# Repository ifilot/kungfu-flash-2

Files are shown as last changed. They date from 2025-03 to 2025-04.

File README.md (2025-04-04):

# Kung Fu Flash 2 - Adapted version

Cartridge for the Commodore 64 that packs a punch.

> [!IMPORTANT]  
> This repository is a fork of [Kung Fu Flash 2](https://github.com/KimJorgensen/KungFuFlash2).
> A number of changes have been made to the original design, mainly focusing
> on using so-called "BASIC" parts to reduce upon the cost of using the JLCPCB
> assembly service.
>
> In the folder [hardware/production](hardware/production) one can find the
> BOM and CPL files for using the JLCPCB assembly service.
>
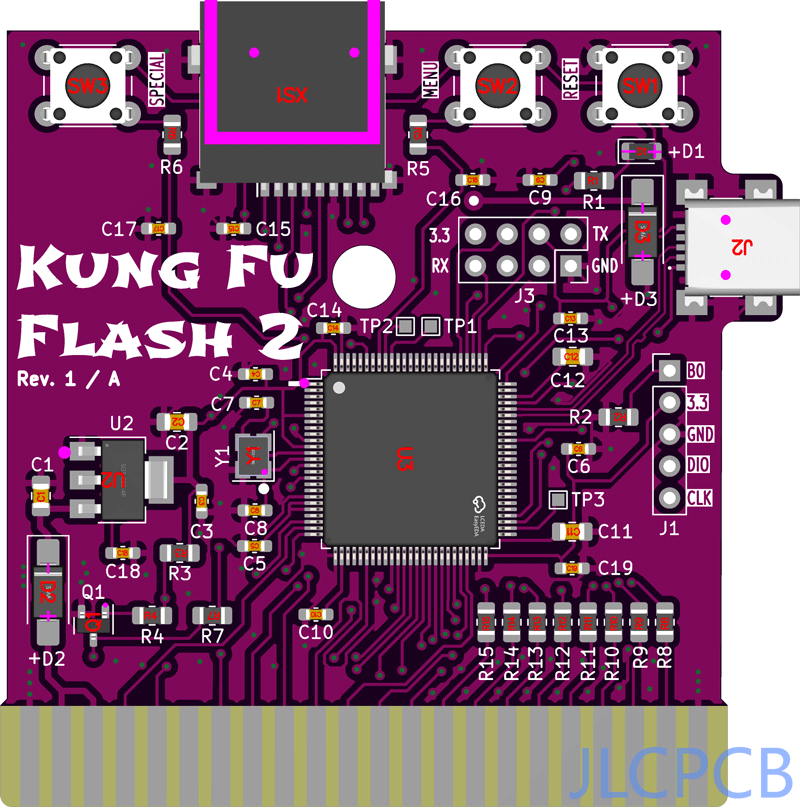
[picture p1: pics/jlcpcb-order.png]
jlcpcb order image
> 

**The text below has been copied verbatim from the original repository**

Kung Fu Flash 2 is the big brother of [Kung Fu Flash](https://github.com/KimJorgensen/KungFuFlash). It has a faster microcontroller with more memory and I/O pins, allowing for additional functionality.

**Currently, this project is considered experimental** and provides the same features as Kung Fu Flash, with these notable exceptions:

* CRT files are loaded into RAM, not flash, making large CRT files startup faster. However, changes to EasyFlash cartridges are lost if power is turned off, unless saved via the menu first
* The cartridge detects if the C64/C128 is reset. This allows the use of an additional reset button on the C64 or the built-in reset button on the C128
* REU emulation has been added

Kung Fu Flash 2 Launcher

Kung Fu Flash 2 can emulate different cartridge types, load PRG files and use D64 disk images.
Just place your desired CRT, PRG or D64 files on a FAT formatted microSD card and use the built-in launcher to execute them.

## Hardware

There are three buttons on the cartridge; a reset button, a menu button for starting the launcher, and a special button that is used by the freezer cartridges.

Cartridge Case

The form factor is similar to Kung Fu Flash and it should be possible to use the same cartridge cases.
It could be the Stumpy Cartridge Case from TFW8b or the 3D printed cartridge case designed by bigby, [see here](https://www.thingiverse.com/thing:4153414).

Kung Fu Flash 2 PCB

The gerber files and BOM can be found [here](https://github.com/KimJorgensen/KungFuFlash2/releases/tag/v2.00).

## Supported Cartridges

The following cartridge types are currently supported:

* Generic cartridge (8k, 16k, Ultimax)
* Action Replay v4.x/v5/v6
* KCS Power Cartridge
* Final Cartridge III(+)
* Simons' BASIC
* Fun Play, Power Play
* Super Games
* Ocean type 1
* Epyx Fastload
* C64 Game System, System 3
* WarpSpeed
* Dinamic
* Zaxxon, Super Zaxxon
* Magic Desk, Domark, HES Australia
* Super Snapshot v5
* Comal-80
* Ross
* EasyFlash
* Prophet64
* Freeze Frame
* Freeze Machine
* MACH 5
* Pagefox
* RGCD, Hucky
* Drean
* C128 Generic cartridge (external function ROM)
* WarpSpeed 128

## Supported File Types

The following file types are currently supported:

* Cartridge (CRT)
* C64/C128 generic cartridge (ROM, BIN)
* Disk image (D64, D71, D81)
* Tape image (T64)
* Program (PRG, P00)
* Firmware update (UPD)
* Text document (TXT, NFO, 1ST)

## REU Emulation

Kung Fu Flash 2 can emulate a 1 Mb REU (RAM Expansion Unit) simultaneously with disk drive emulation.
The REU is enabled in the settings menu (F5) and active when:

* A program is executed using the default option (RETURN)
* A disk image or directory is mounted using "Mount" in the file options menu (SHIFT+RETURN)
* BASIC is started via F6 (C128) or F7 (C64) in the launcher

The REU will not be active when emulating cartridges (CRT files)

## USB Port

The USB port allows programs or disk images to be transferred from/to a PC using the EasyFlash 3 USB protocol.
The USB port is active when:

* The Kung Fu Flash 2 launcher is running
* A program is started using "Load" in the file options menu (SHIFT+RETURN)
* BASIC is started via F7 in the launcher **and** REU emulation is disabled in the settings menu (F5)

Kung Fu Flash 2 shows up as a standard serial port when connected to a PC not requiring any custom drivers to be installed.
This means, however, that the EasyFlash 3 program on the PC side must be modified to support Kung Fu Flash.

The repository of the original Kung Fu Flash contains a modified version of [EasyFlash 3 USB Utilities](https://github.com/KimJorgensen/KungFuFlash/tree/master/3rd_party/ef3utils)
and [EasyFlash 3 BBS](https://github.com/KimJorgensen/KungFuFlash/tree/master/3rd_party/ef3bbs) which will also work with the Kung Fu Flash 2.

## Firmware Update

Just place the KungFuFlash_v2.xx.upd file on the SD card and select the file in the launcher to initiate the firmware update.
The newest firmware can be found [here](https://github.com/KimJorgensen/KungFuFlash2/releases/).

For initial firmware installation, [see here](firmware/README.md).

## Limitations

Kung Fu Flash 2 is a so called Software Defined Cartridge where a fast microcontroller emulates cartridge hardware in software.
This makes it extremely flexible, allowing different cartridge types to be supported at a relative low cost.

However, it can be challenging to get the C64 bus timing correct in software and in some places the timing is very close to the limit.
Even though Kung Fu Flash 2 has been tested on different models of the Commodore 64, there is a chance that it doesn't work correctly on your specific model, or requires [phi2 offset adjustment](firmware/README.md#diagnostic).
Use it at your own risk!

Kung Fu Flash 2 will work with the PAL and NTSC version of the Commodore 64 or Commodore 128.

Disk drive emulation is using kernal vectors and will not work with fast loaders or software that uses direct hardware access which a lot of games does.
Currently REL files are not supported and only a subset of the Commodore DOS commands are supported.

## Thanks

Kung Fu Flash 2 was based on or uses other open source projects:

* [Kung Fu Flash](https://github.com/KimJorgensen/KungFuFlash)
* [EasyFlash 3](https://bitbucket.org/skoe/easyflash) by Thomas Giesel
* [Draco Browser](https://csdb.dk/release/?id=89910) by Sascha Bader
* [fatfs-stm32](https://github.com/colosimo/fatfs-stm32) by Aurelio Colosimo
* [FatFs](http://elm-chan.org/fsw/ff/00index_e.html) by ChaN
* [libusb_stm32](https://github.com/dmitrystu/libusb_stm32) by Dmitry Filimonchuk
* [OpenC64Cart](https://github.com/SukkoPera/OpenC64Cart) by Giorgioggì
* [Disk2easyflash](https://csdb.dk/release/?id=150323) by ALeX Kazik

and a few others. Please check the individual files for their license.

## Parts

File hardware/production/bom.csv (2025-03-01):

Designator | Footprint | Quantity | Value | LCSC Part #
C1, C2 | 0805 | 2 | 10uF | C15850
C10, C13, C14, C15, C16, C17, C18, C19, C3, C4, C5, C6, C9 | 0603 | 13 | 100nF | C14663
C11, C12 | 0805 | 2 | 2.2uF | C377773
C7, C8 | 0603 | 2 | 20pF | C1648
D1 | 0805 | 1 | LED | C2297
D2, D3 | D_SMA_Handsoldering | 2 | D_Schottky | C14996
J1 | PinHeader_1x05_P2.54mm_Vertical | 1 | SWD
J2 | Conn_USBmini_reichelt | 1 | USB_B_Micro | C46391
J3 | PinSocket_2x04_P2.54mm_Vertical | 1 | Wifi
Q1 | SOT-23 | 1 | BC817 | C466643
R1, R4, R5, R6, R7 | 0805 | 5 | 510R | C17734
R10, R11, R12, R13, R14, R15, R8, R9 | 0805 | 8 | 100R | C17408
R2, R3 | 0805 | 2 | 10k | C17414
SW1 | SW_PUSH_6mm_H8mm | 1 | Reset | C134186
SW2 | SW_PUSH_6mm_H8mm | 1 | Menu | C134186
SW3 | SW_PUSH_6mm_H8mm | 1 | Special | C134186
TP1, TP2, TP3 | TestPoint_Pad_1.0x1.0mm | 3 | ~
U1 | C64-Cart | 1 | C64-Exp-Port
U2 | SOT-223-3_TabPin2 | 1 | AMS1117-3.3 | C6186
U3 | LQFP-100_14x14mm_P0.5mm | 1 | STM32H7B0VBTx | C730227
XS1 | Conn_uSDcard | 1 | uSD_push_push | C91145
Y1 | Crystal_SMD_3225-4Pin_3.2x2.5mm | 1 | 25 MHz | C9006

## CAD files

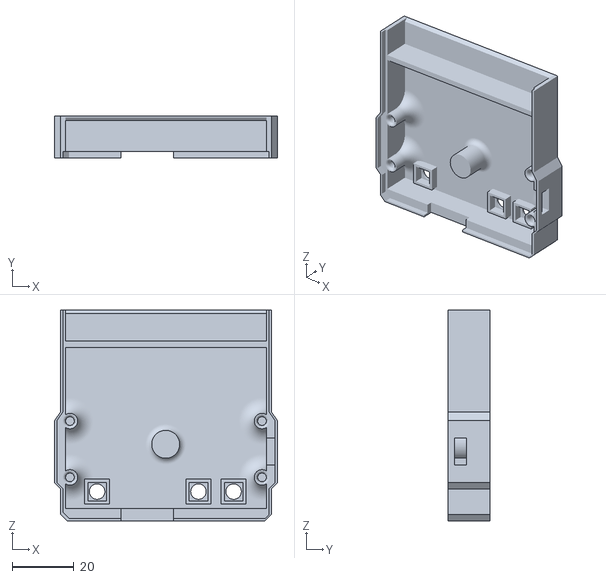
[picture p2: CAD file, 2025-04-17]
enclosure/top.stl
72.0 x 13.5 x 68.0

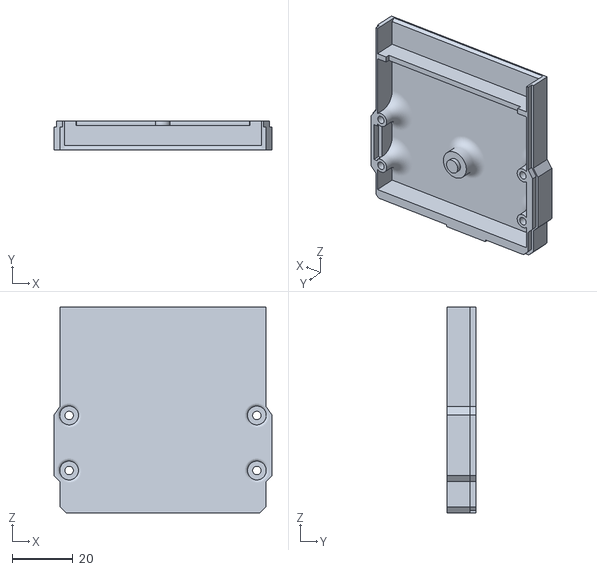
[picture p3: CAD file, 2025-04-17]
enclosure/bottom.stl
72.0 x 9.73 x 68.0

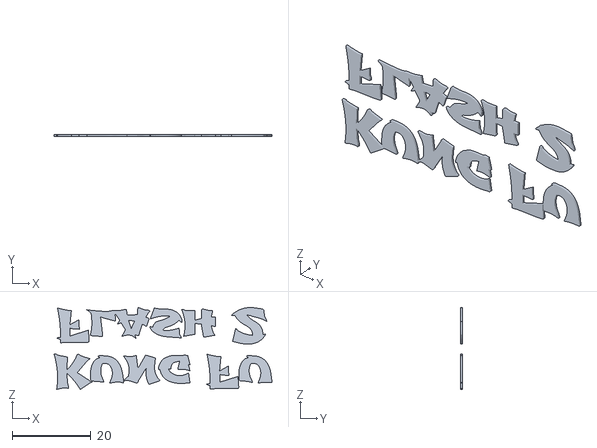
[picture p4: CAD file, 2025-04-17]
enclosure/label.stl
55.4 x 0.5 x 20.9

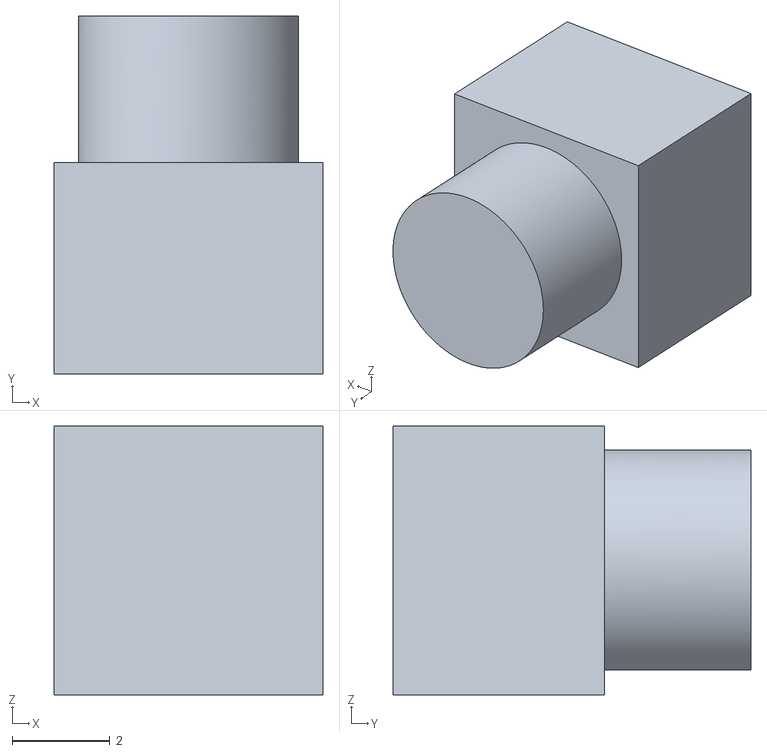
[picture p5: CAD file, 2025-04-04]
enclosure/button.stl
5.50 x 7.32 x 5.50

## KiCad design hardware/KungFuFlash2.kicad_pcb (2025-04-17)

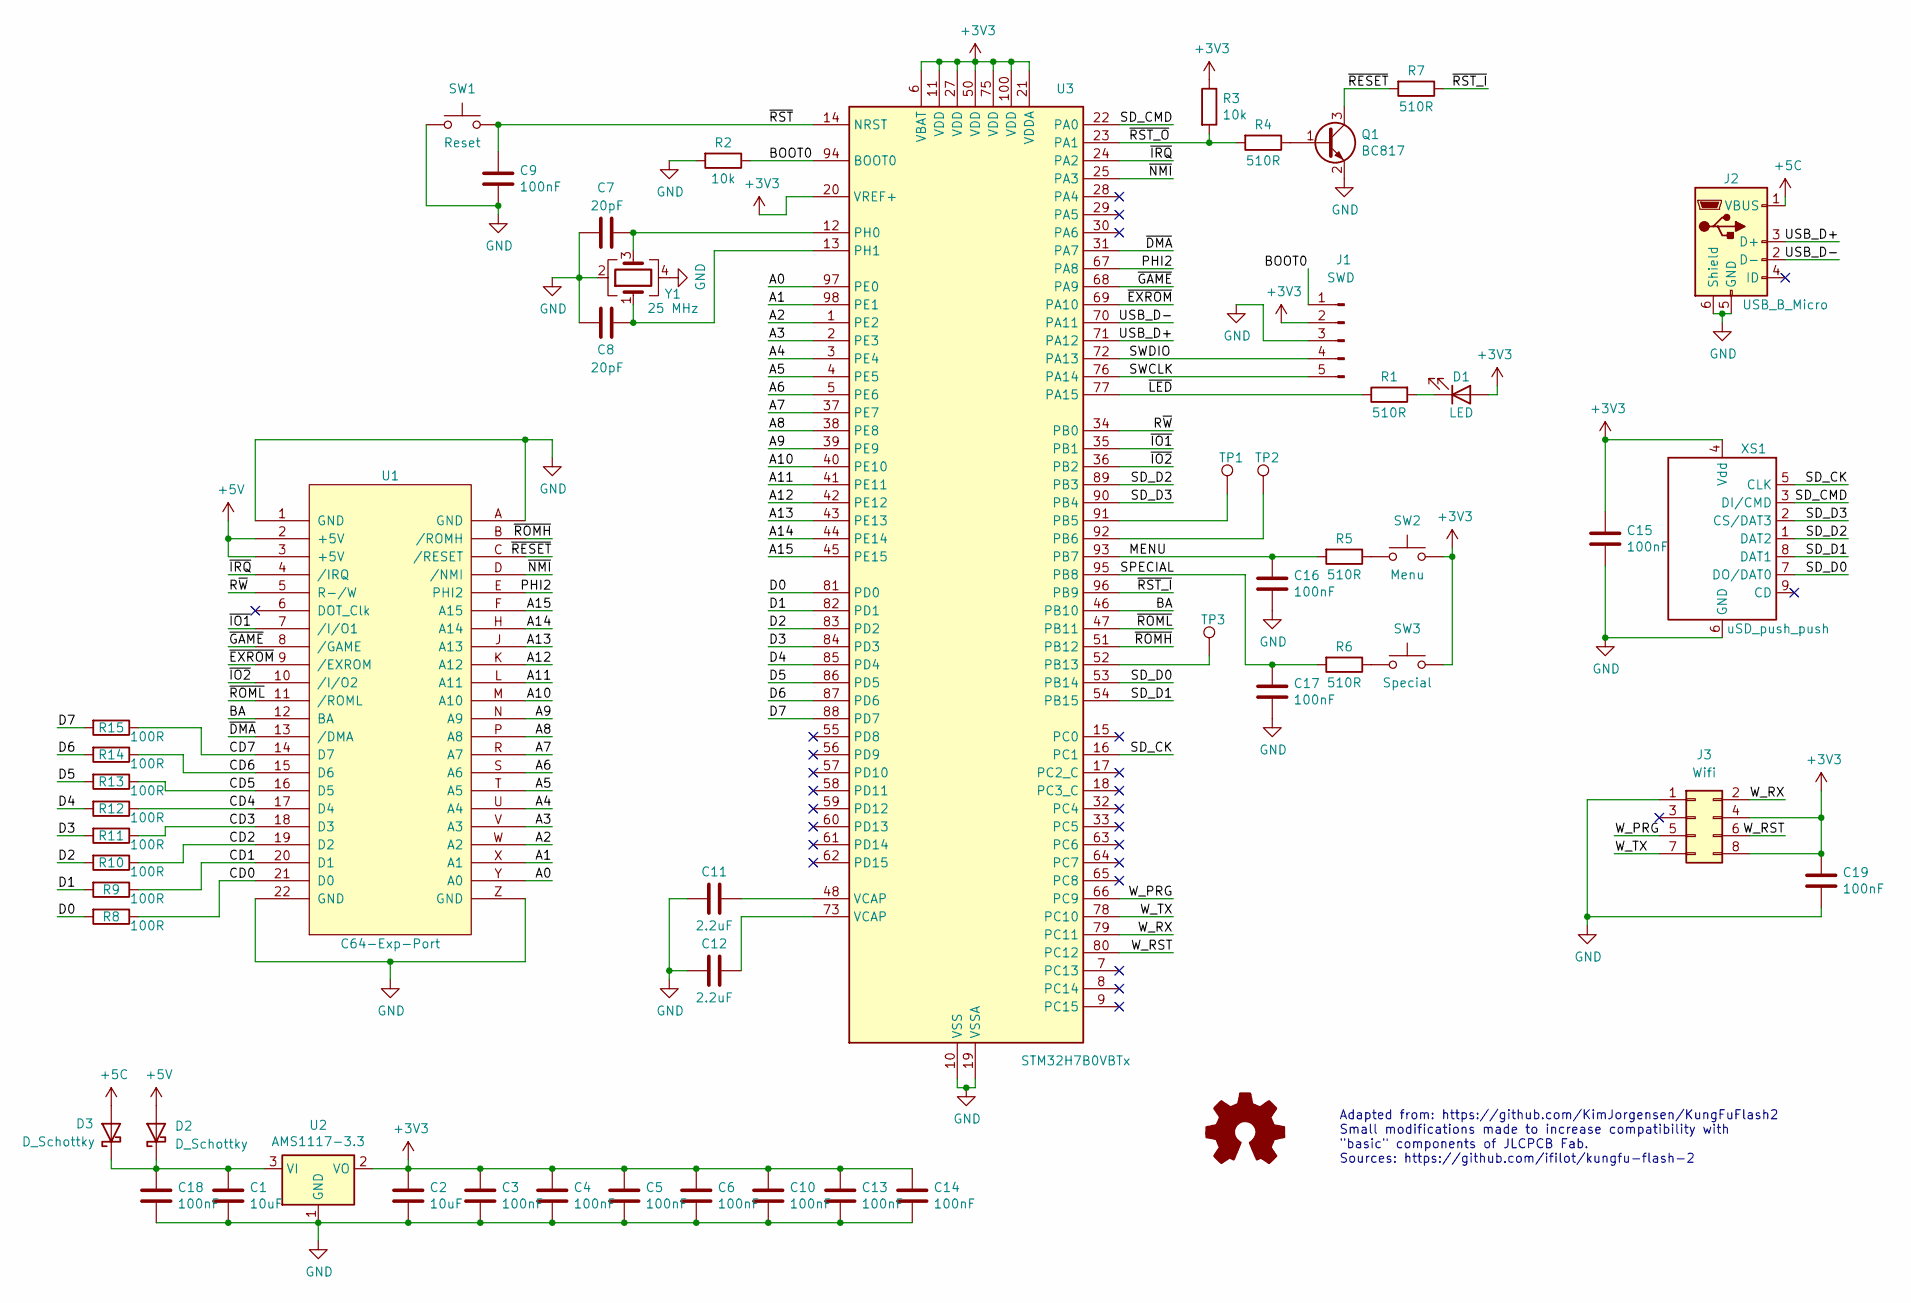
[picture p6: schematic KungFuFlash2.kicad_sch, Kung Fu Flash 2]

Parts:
C1, C2: 10uF; C_0805_2012Metric_Pad1.18x1.45mm_HandSolder; LCSC Part # C15850
C3, C4, C5, C6, C9, C10, C13, C14, C15, C16, C17, C18, C19: 100nF; C_0603_1608Metric_Pad1.08x0.95mm_HandSolder; LCSC Part # C14663
C7, C8: 20pF; C_0603_1608Metric_Pad1.08x0.95mm_HandSolder; LCSC Part # C1648
C11, C12: 2.2uF; C_0805_2012Metric_Pad1.18x1.45mm_HandSolder; LCSC Part # C377773
D1: LED; LED_0805_2012Metric_Pad1.15x1.40mm_HandSolder; LCSC Part # C2297
D2, D3: D_Schottky; D_SMA_Handsoldering; LCSC Part # C14996
J1: SWD; PinHeader_1x05_P2.54mm_Vertical
J2: USB_B_Micro; Conn_USBmini_reichelt; LCSC Part # C46391
J3: Wifi; PinSocket_2x04_P2.54mm_Vertical
Q1: BC817; SOT-23; LCSC Part # C466643
R1, R4, R5, R6, R7: 510R; R_0805_2012Metric_Pad1.20x1.40mm_HandSolder; LCSC Part # C17734
R2, R3: 10k; R_0805_2012Metric_Pad1.20x1.40mm_HandSolder; LCSC Part # C17414
R8, R9, R10, R11, R12, R13, R14, R15: 100R; R_0805_2012Metric_Pad1.20x1.40mm_HandSolder; LCSC Part # C17408
SW1: Reset; SW_PUSH_6mm_H8mm; LCSC Part # C134186
SW2: Menu; SW_PUSH_6mm_H8mm; LCSC Part # C134186
SW3: Special; SW_PUSH_6mm_H8mm; LCSC Part # C134186
TP1, TP2, TP3: TestPoint_Pad_1.0x1.0mm
U1: C64-Exp-Port; C64-Cart
U2: AMS1117-3.3; SOT-223-3_TabPin2; LCSC Part # C6186
U3: STM32H7B0VBTx; LQFP-100_14x14mm_P0.5mm; LCSC Part # C730227
XS1: uSD_push_push; Conn_uSDcard; LCSC Part # C91145
Y1: 25 MHz; Crystal_SMD_3225-4Pin_3.2x2.5mm; LCSC Part # C9006

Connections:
+3V3: C2.1, C3.1, C4.1, C5.1, C6.1, C10.1, C13.1, C14.1, C15.1, C19.1, D1.2 (A), J1.2, J3.4, J3.8, R3.1, SW2.1, SW3.1, U2.2 (VO), U3.6 (VBAT), U3.11 (VDD), U3.20 (VREF+), U3.21 (VDDA), U3.27 (VDD), U3.50 (VDD), U3.75 (VDD), U3.100 (VDD), XS1.4 (Vdd)
+5C: D3.2 (A), J2.1 (VBUS)
+5V: D2.2 (A), U1.2 (+5V), U1.3 (+5V)
/A0: U1.Y (A0), U3.97 (PE0)
/A1: U1.X (A1), U3.98 (PE1)
/A2: U1.W (A2), U3.1 (PE2)
/A3: U1.V (A3), U3.2 (PE3)
/A4: U1.U (A4), U3.3 (PE4)
/A5: U1.T (A5), U3.4 (PE5)
/A6: U1.S (A6), U3.5 (PE6)
/A7: U1.R (A7), U3.37 (PE7)
/A8: U1.P (A8), U3.38 (PE8)
/A9: U1.N (A9), U3.39 (PE9)
/A10: U1.M (A10), U3.40 (PE10)
/A11: U1.L (A11), U3.41 (PE11)
/A12: U1.K (A12), U3.42 (PE12)
/A13: U1.J (A13), U3.43 (PE13)
/A14: U1.H (A14), U3.44 (PE14)
/A15: U1.F (A15), U3.45 (PE15)
/BA: U1.12 (BA), U3.46 (PB10)
/BOOT0: J1.1, R2.1, U3.94 (BOOT0)
/CD0: R8.1, U1.21 (D0)
/CD1: R9.1, U1.20 (D1)
/CD2: R10.1, U1.19 (D2)
/CD3: R11.1, U1.18 (D3)
/CD4: R12.1, U1.17 (D4)
/CD5: R13.1, U1.16 (D5)
/CD6: R14.1, U1.15 (D6)
/CD7: R15.1, U1.14 (D7)
/D0: R8.2, U3.81 (PD0)
/D1: R9.2, U3.82 (PD1)
/D2: R10.2, U3.83 (PD2)
/D3: R11.2, U3.84 (PD3)
/D4: R12.2, U3.85 (PD4)
/D5: R13.2, U3.86 (PD5)
/D6: R14.2, U3.87 (PD6)
/D7: R15.2, U3.88 (PD7)
/MENU: C16.1, R5.2, U3.93 (PB7)
/PHI2: U1.E (PHI2), U3.67 (PA8)
/R~W: U1.5 (R-/W), U3.34 (PB0)
/SD_CK: U3.16 (PC1), XS1.5 (CLK)
/SD_CMD: U3.22 (PA0), XS1.3 (DI/CMD)
/SD_D0: U3.53 (PB14), XS1.7 (DO/DAT0)
/SD_D1: U3.54 (PB15), XS1.8 (DAT1)
/SD_D2: U3.89 (PB3), XS1.1 (DAT2)
/SD_D3: U3.90 (PB4), XS1.2 (CS/DAT3)
/SPECIAL: C17.1, R6.2, U3.95 (PB8)
/SWCLK: J1.5, U3.76 (PA14)
/SWDIO: J1.4, U3.72 (PA13)
/USB_D+: J2.3 (D+), U3.71 (PA12)
/USB_D-: J2.2 (D-), U3.70 (PA11)
/W_PRG: J3.5, U3.66 (PC9)
/W_RST: J3.6, U3.80 (PC12)
/W_RX: J3.2, U3.79 (PC11)
/W_TX: J3.7, U3.78 (PC10)
/~DMA: U1.13 (/DMA), U3.31 (PA7)
/~EXROM: U1.9 (/EXROM), U3.69 (PA10)
/~GAME: U1.8 (/GAME), U3.68 (PA9)
/~IO1: U1.7 (/I/O1), U3.35 (PB1)
/~IO2: U1.10 (/I/O2), U3.36 (PB2)
/~IRQ: U1.4 (/IRQ), U3.24 (PA2)
/~LED: R1.1, U3.77 (PA15)
/~NMI: U1.D (/NMI), U3.25 (PA3)
/~RESET: Q1.3 (C), R7.2, U1.C (/RESET)
/~ROMH: U1.B (/ROMH), U3.51 (PB12)
/~ROML: U1.11 (/ROML), U3.47 (PB11)
/~RST_I: R7.1, U3.96 (PB9)
/~RST_O: R3.2, R4.2, U3.23 (PA1)
/~RST: C9.1, SW1.2, U3.14 (NRST)
GND: C1.2, C2.2, C3.2, C4.2, C5.2, C6.2, C7.1, C8.1, C9.2, C10.2, C11.1, C12.2, C13.2, C14.2, C15.2, C16.2, C17.2, C18.2, C19.2, J1.3, J2.5 (GND), J2.6 (Shield), J3.1, Q1.2 (E), R2.2, SW1.1, U1.1 (GND), U1.22 (GND), U1.A (GND), U1.Z (GND), U2.1 (GND), U3.10 (VSS), U3.19 (VSSA), U3.26 (VSS), U3.49 (VSS), U3.74 (VSS), U3.99 (VSS), XS1.6 (GND), Y1.2, Y1.4
unnamed: C11.2, U3.48 (VCAP)
unnamed: C12.1, U3.73 (VCAP)
unnamed: D1.1 (K), R1.2
unnamed: C1.1, C18.1, D2.1 (K), D3.1 (K), U2.3 (VI)
unnamed: Q1.1 (B), R4.1
unnamed: R5.1, SW2.2
unnamed: R6.1, SW3.2
unnamed: TP1.1, U3.91 (PB5)
unnamed: TP2.1, U3.92 (PB6)
unnamed: TP3.1, U3.52 (PB13)
unnamed: C7.2, U3.12 (PH0), Y1.3
unnamed: C8.2, U3.13 (PH1), Y1.1

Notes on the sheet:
Adapted from: https://github.com/KimJorgensen/KungFuFlash2 Small modifications made to increase compatibility with "basic" components of JLCPCB Fab. Sources: https://github.com/ifilot/kungfu-flash-2

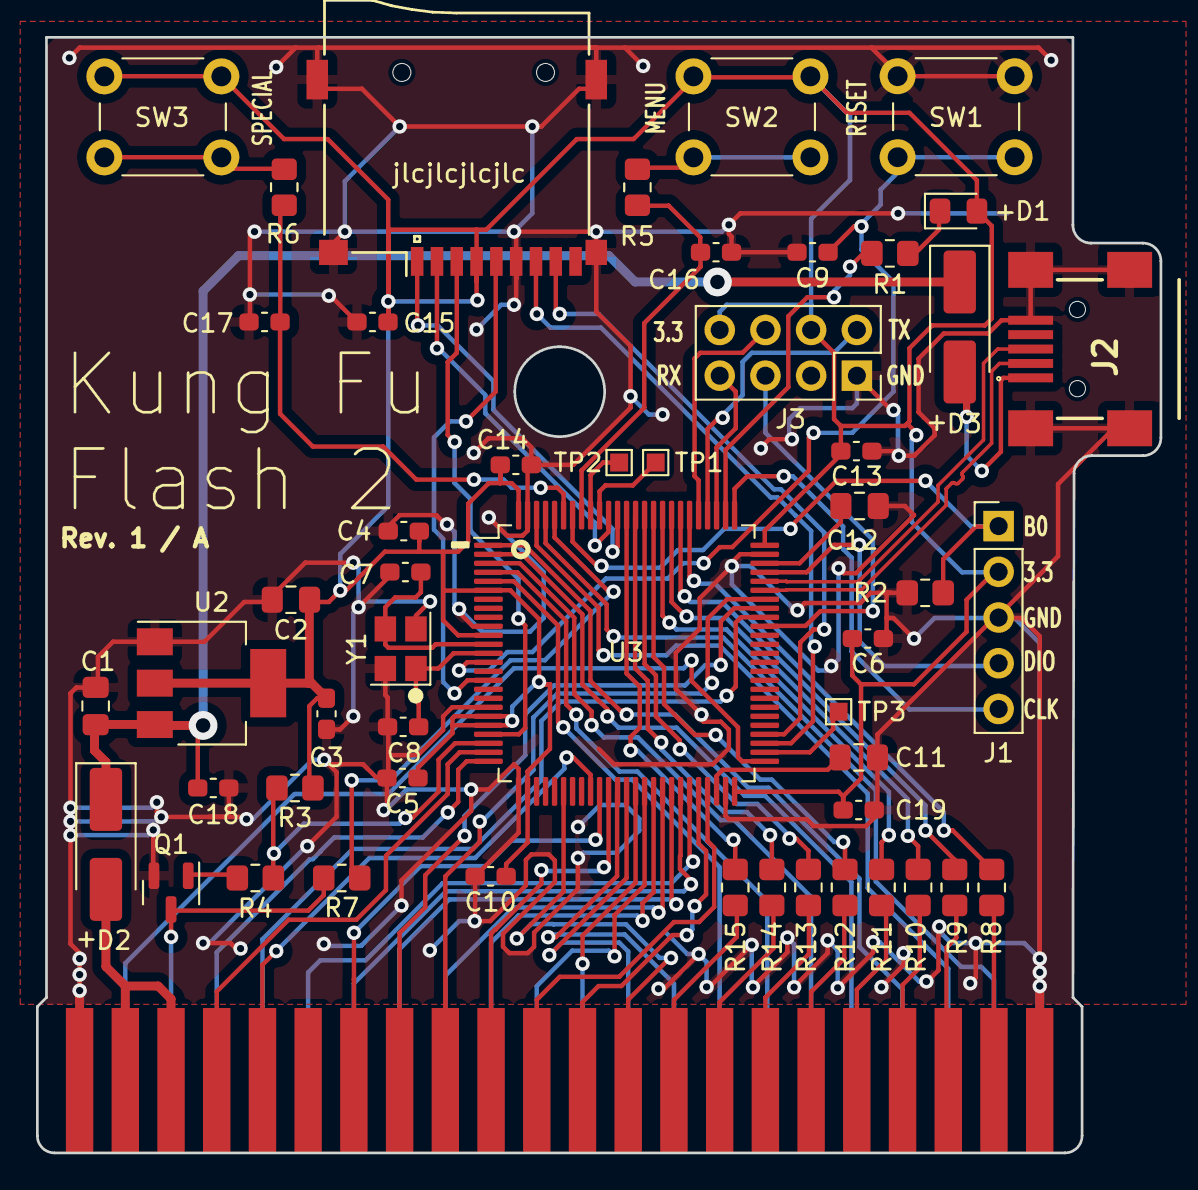
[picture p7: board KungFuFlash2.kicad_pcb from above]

Board: 2 copper layers, 62.4 x 62.0 mm, 52 parts (0 on the bottom side), 82 nets.

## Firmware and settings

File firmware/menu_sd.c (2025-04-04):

/*
 * Copyright (c) 2019-2025 Kim Jørgensen
 *
 * This software is provided 'as-is', without any express or implied
 * warranty.  In no event will the authors be held liable for any damages
 * arising from the use of this software.
 *
 * Permission is granted to anyone to use this software for any purpose,
 * including commercial applications, and to alter it and redistribute it
 * freely, subject to the following restrictions:
 *
 * 1. The origin of this software must not be misrepresented; you must not
 *    claim that you wrote the original software. If you use this software
 *    in a product, an acknowledgment in the product documentation would be
 *    appreciated but is not required.
 * 2. Altered source versions must be plainly marked as such, and must not be
 *    misrepresented as being the original software.
 * 3. This notice may not be removed or altered from any source distribution.
 */

static void sd_format_size(char *buffer, u32 size)
{
    char units[] = "BKmg";
    char *unit = units;

    while (size >= 1000)
    {
        size += 24;
        size /= 1024;
        unit++;
    }

    if (size < 100)
    {
        *buffer++ = ' ';
    }
    if (size < 10)
    {
        *buffer++ = ' ';
    }

    sprint(buffer, " %u%c", size, *unit);
}

static void sd_format_element(char *buffer, FILINFO *info)
{
    *buffer++ = ' ';

    // Element name
    const u8 filename_len = (ELEMENT_LENGTH-1)-5;
    to_petscii_pad(buffer, info->fname, filename_len);
    buffer += filename_len;

    // Element type or size
    if (info->fattrib & AM_DIR)
    {
        sprint(buffer, "  dir");
    }
    else
    {
        sd_format_size(buffer, info->fsize);
    }
}

static void sd_send_not_found(SD_STATE *state)
{
    to_petscii_pad(scratch_buf, " no files found", ELEMENT_LENGTH);
    if (state->search[0])
    {
        scratch_buf[0] = SELECTED_ELEMENT;
    }

    c64_send_data(scratch_buf, ELEMENT_LENGTH);
}

static u8 sd_send_page(SD_STATE *state, u8 selected_element)
{
    bool send_dot_dot = !state->in_root && state->page_no == 0;
    bool send_not_found = state->page_no == 0;

    FILINFO file_info;
    u8 element;
    for (element=0; element<MAX_ELEMENTS_PAGE; element++)
    {
        if (send_dot_dot)
        {
            file_info.fname[0] = '.';
            file_info.fname[1] = '.';
            file_info.fname[2] = 0;
            file_info.fattrib = AM_DIR;
            send_dot_dot = false;
        }
        else
        {
            if (!dir_read(&state->end_page, &file_info))
            {
                file_info.fname[0] = 0;
            }

            if (file_info.fname[0])
            {
                send_not_found = false;
            }
            else
            {
                // End of dir
                dir_close(&state->end_page);
                state->dir_end = true;

                if (send_not_found)
                {
                    sd_send_not_found(state);
                }

                send_page_end();
                break;
            }
        }

        sd_format_element(scratch_buf, &file_info);
        if (element == selected_element)
        {
            scratch_buf[0] = SELECTED_ELEMENT;
        }

        c64_send_data(scratch_buf, ELEMENT_LENGTH);
    }

    return element;
}

static void sd_dir_open(SD_STATE *state)
{
    // Append star to end of search string
    size_t search_len = strlen(state->search);
    if (search_len && state->search[search_len-1] != '*')
    {
        state->search[search_len] = '*';
        state->search[search_len + 1] = 0;
    }

    if (!dir_open(&state->start_page, state->search))
    {
        fail_to_read_sd();
    }

    state->end_page = state->start_page;
    state->page_no = 0;
    state->dir_end = false;
}

static void sd_send_prg_message(const char *message)
{
    c64_send_prg_message(message);
    c64_interface(false);
}

static void sd_send_warning_restart(const char *message, const char *filename)
{
    c64_interface_sync();
    sprint(scratch_buf, "%s\r\n\r\n%s", message, filename);
    c64_send_warning(scratch_buf);
    restart_to_menu();
}

static u8 sd_parse_file_number(char *filename, u8 *extension)
{
    u8 pos = *extension-1;
    if (pos <= 5 || filename[pos--] != ')')
    {
        return 0;
    }

    u8 number;
    if (filename[pos] >= '0' && filename[pos] <= '9')
    {
        number = filename[pos--] - '0';
    }
    else
    {
        return 0;
    }

    if (filename[pos] >= '0' && filename[pos] <= '9')
    {
        number += (filename[pos--] - '0') * 10;
    }

    if (filename[pos--] != '(' || filename[pos] != ' ')
    {
        return 0;
    }

    *extension = pos;
    return number;
}

static bool sd_generate_new_filename(void)
{
    char *filename = cfg_file.file;

    u8 extension;
    u8 length = get_filename_length(filename, &extension);
    if (length <= extension)
    {
        return false;
    }

    u8 file_number = sd_parse_file_number(filename, &extension);
    if (++file_number >= 100)
    {
        return false;
    }

    if (length < (sizeof(cfg_file.file)-5))
    {
        sprint(filename + extension, " (%u).crt", file_number);
        return true;
    }

    return false;
}

static void sd_handle_save_updated_crt(u8 flags)
{
    sd_send_prg_message("Saving CRT file.");
    if (!load_cfg())
    {
        restart_to_menu();
    }

    if (!(flags & SELECT_FLAG_OVERWRITE))
    {
        bool file_exists = true;
        while (file_exists)
        {
            if (!sd_generate_new_filename())
            {
                if (!load_cfg())
                {
                    restart_to_menu();
                }
                sd_send_warning_restart("Failed to generate new filename for",
                                        cfg_file.file);
            }

            FILINFO file_info;
            file_exists = file_stat(cfg_file.file, &file_info);
        }
    }

    u8 banks = 0;
    FIL file;
    if (!file_open(&file, cfg_file.file, FA_WRITE|FA_CREATE_ALWAYS) ||
        !crt_write_header(&file, CRT_EASYFLASH, 1, 0, "EASYFLASH") ||
        !(banks = crt_write_file(&file)))
    {
        sd_send_warning_restart("Failed to write CRT file", cfg_file.file);
    }
    file_close(&file);

    crt_buf_valid(banks);
    save_cfg();
    restart_to_menu();
}

static bool sd_crt_updated(SD_STATE *state)
{
    if (cfg_file.boot_type != CFG_CRT ||
        cfg_file.crt.type != CRT_EASYFLASH ||
        !cfg_file.file[0] ||
        !crt_buf_is_updated() ||
        state->ignore_crt_updated)
    {
        return false;
    }

    state->ignore_crt_updated = true;   // Don't ask to save file again
    return true;
}
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

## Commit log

2025-03-01 Adapting board for JLCPCB ordering
    [KungFuFlash2-B_Cu.gbl, KungFuFlash2-B_Mask.gbs, KungFuFlash2-B_Paste.gbp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]
2025-03-01 Refining design and updating README.md
    [KungFuFlash2-B_Cu.gbl, KungFuFlash2-B_Mask.gbs, KungFuFlash2-B_Paste.gbp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]
2025-03-01 Filling out all components
    [KungFuFlash2.kicad_pcb, KungFuFlash2.kicad_sch, bom.csv]
2025-03-01 Fixing wrong component
    [KungFuFlash2.kicad_pcb, KungFuFlash2.kicad_sch, bom.csv]
2025-04-04 Adding enclosure
    [KungFuFlash2-B_Cu.gbl, KungFuFlash2-B_Mask.gbs, KungFuFlash2-B_Paste.gbp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]
2025-04-17 Adding flash procedure
    [KungFuFlash2.kicad_pcb, bottom.stl, label.stl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]
